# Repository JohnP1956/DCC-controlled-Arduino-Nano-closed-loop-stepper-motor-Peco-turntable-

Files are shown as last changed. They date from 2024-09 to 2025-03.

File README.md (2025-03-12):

This is my project to construct a OO gauge Peco turntable kit motorised with a Makerbase MKS42D closed loop stepper motor.  The construction details are in the RMweb link.  The user guide for the motor is attached as is the arduino code I developed to control the motor.  The code was developed using AI (Chat GPT, CoPilot and Claude) as I am not a coder.  I have also added a demo code for controling the turntable system with RR&CO Train Controller (Gold).
I recently noticed that MKS have updated their product to a serial commanded motor only.  However, the motor I used and its previous incarnation plus the kit to add a closed loop board to any NEMA 17 motor are still available on Aliexpress at the time of writing this README note (March 2025).
Readers should note that the PCB does not include a 5volt connection for the stepper motor.  This is bacause the original wiring information for the motor did not include the need for the 5 volt connection.  I used a direct wire to the VCC terminal of the hall detector connection on the pcb.  You can either do the same, wire a shunt wire on the underside of the pcb or update the pcb layout.  Either way the 5 volt connetion (white wire on the motor lead) must be connected or the motor will not move.

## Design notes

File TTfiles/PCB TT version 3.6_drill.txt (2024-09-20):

; NON-PLATED HOLES START AT T1
; THROUGH (PLATED) HOLES START AT T100
M48
INCH
T1C0.086614
T100C0.036000
T101C0.027559
T102C0.038000
T103C0.040000
T104C0.035000
T105C0.035433
T106C0.015748
T107C0.042000
%
T1
X036866Y019914
X036866Y001734
X002614Y001734
T100
X013722Y005381
X003722Y011381
X004722Y005381
X014722Y011381
X003722Y005381
X014722Y005381
X004722Y011381
X013722Y011381
X006722Y005381
X009722Y011381
X016722Y011381
X011722Y005381
X010722Y011381
X012722Y005381
X002722Y011381
X008722Y005381
X005722Y005381
X007722Y005381
X015722Y011381
X015722Y005381
X005722Y011381
X007722Y011381
X002722Y005381
X012722Y011381
X008722Y011381
X011722Y011381
X010722Y005381
X016722Y005381
X006722Y011381
X009722Y005381
T101
X022663Y016424
X025108Y003279
X032722Y007381
X029722Y005381
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

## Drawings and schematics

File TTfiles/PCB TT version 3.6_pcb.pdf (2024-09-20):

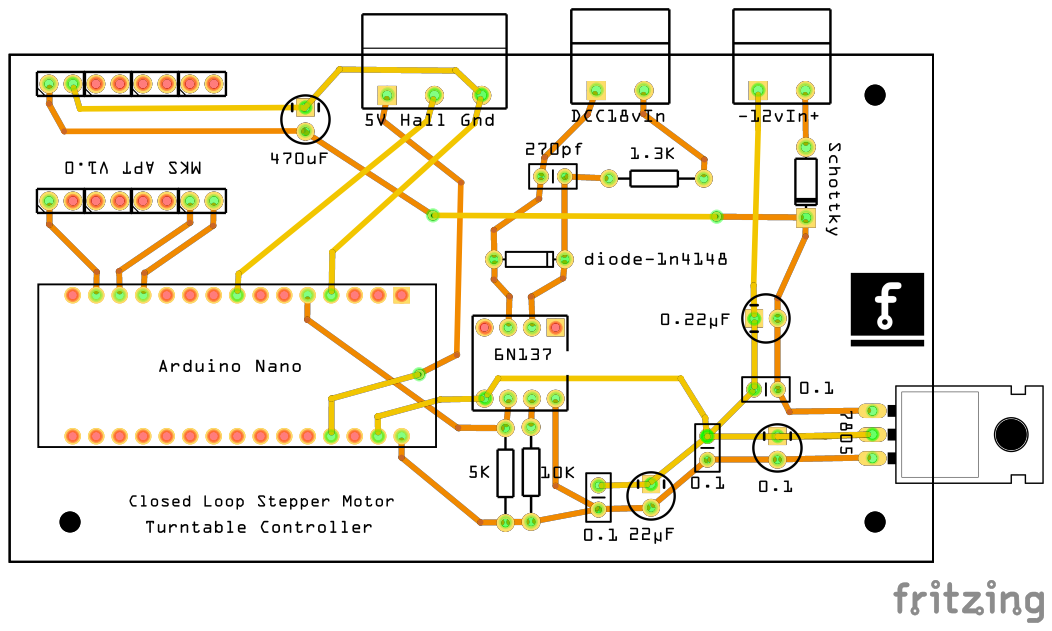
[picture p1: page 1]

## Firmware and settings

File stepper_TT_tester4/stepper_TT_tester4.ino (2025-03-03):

/*
 * Stepper Motor Turntable Control with DCC Commands
 *
 * This software controls a stepper motor for a model railway turntable, using DCC commands
 * to move the turntable to various indexed positions. It supports an iterative setup process
 * for configuring index positions, storing configurations in EEPROM, and ensuring compliance
 * with NMRA DCC standards.
 *
 * Key Features:
 * - DCC control with address validation (addresses 1-511).
 * - Iterative setup process with EEPROM storage and `EEPROM.update()` for efficient writes.
 * - Configurable homing direction (clockwise or counter-clockwise, default is now counter-clockwise).
 * - Debug mode for serial communication during setup.
 * - It allows for iterative setup of each index position, viewing and modifying stored positions,
 *  -and uses EEPROM.update() to write only if a value changes.
 * - Supports 1.8-degree stepper motor with 32x microstepping (6400 steps per revolution).
 * - Configurable number of index positions (1-12)
 * - License: MIT License (see below).
 *
 * Libraries Used:
 * - AccelStepper: https://www.airspayce.com/mikem/arduino/AccelStepper/
 * - NmraDcc: https://github.com/mrrwa/NmraDcc
 *
 * Author: JP1 c/o RM Web
 * Date: 20/07/2024
 *
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
 */

#include <AccelStepper.h>
#include <NmraDcc.h>
#include <EEPROM.h>
#include "config.h"

// Create an instance of the AccelStepper class
AccelStepper stepper(MotorInterfaceType, stepPin, dirPin);

// Create an instance of the DCC decoder
NmraDcc Dcc;

// Position-related variables
long magnetEndPositions[MAX_INDEX_POSITIONS];    // Positions for magnet end, stored in EEPROM
long nonMagnetEndPositions[MAX_INDEX_POSITIONS]; // Positions for non-magnet end, stored in EEPROM
long currentPosition = 0;
bool homed = false;

// DCC addresses
int homePositionAddress;
int magnetEndAddresses[MAX_INDEX_POSITIONS];
int nonMagnetEndAddresses[MAX_INDEX_POSITIONS];
int numIndexPositions;  // Number of index positions, stored in EEPROM

// Last Address variables to prevent duplicate events
uint16_t lastAddr = 0xFFFF;
uint8_t lastDirection = 0xFF;

// Function prototypes
int getValidDccAddress();
int getValidIndexNumber();
void debugSetup();
String getUserInput();
long getUserInputLong();
bool getUserYesNo();
void loadConfigurations();
void homeMotor();
void moveToPosition(long position);
void moveRelative(long steps);
int calculateShortestStepDifference(long currentPosition, long nextPosition);

void setup() {
  Serial.begin(9600); // Start serial communication for debugging

  // Initialize pins
  pinMode(enPin, OUTPUT);
  pinMode(hallPin, INPUT_PULLUP);
  pinMode(stepPin, OUTPUT);
  pinMode(dirPin, OUTPUT);
  digitalWrite(enPin, LOW); // Enable the motor

  // Set max speed and acceleration
  stepper.setMaxSpeed(maxSpeed);
  stepper.setAcceleration(acceleration);

  Serial.println(F("Setup complete, loading configurations..."));

  // Load configurations from EEPROM
  loadConfigurations();

  // Initialize DCC decoder
  Dcc.pin(0,DCC_PIN, 1);
  Dcc.init(MAN_ID_DIY, 10, CV29_ACCESSORY_DECODER | CV29_OUTPUT_ADDRESS_MODE, 0);// Adjust manufacturer ID and version as needed
  Serial.println(F("DCC decoder initialized"));
  
  // Home the motor at startup
  homeMotor();

  // Call the debug setup function if debugging is enabled
  if (debug) {
    Serial.println(F("Debug mode enabled. Calling debug setup..."));
    debugSetup();
    Serial.println(F("Returned from debug setup..."));
  }
}

void loop() {
  // Process DCC commands
  Dcc.process();

  // Ensure the motor is running
  stepper.run();
}

// DCC command notification handler
void notifyDccAccTurnoutOutput(uint16_t Addr, uint8_t Direction, uint8_t OutputPower) {
  Serial.print(F("DCC Command Received - Address: "));
  Serial.print(Addr);
  Serial.print(F(" Direction: "));
  Serial.print(Direction);
  Serial.print(F(" Power: "));
  Serial.println(OutputPower);

  if (OutputPower) {
    if (Addr == homePositionAddress) {
      Serial.println(F("Moving to home position..."));
      moveRelative(-currentPosition);
      return;
    }

    for (int i = 0; i < numIndexPositions; i++) {
      if (Addr == magnetEndAddresses[i]) {
        Serial.print(F("Moving to magnet end position: "));
        Serial.println(magnetEndPositions[i]);
        long stepsToMove = calculateShortestStepDifference(currentPosition, magnetEndPositions[i]);
        moveRelative(stepsToMove);
        return;
      } else if (Addr == nonMagnetEndAddresses[i]) {
        Serial.print(F("Moving to non-magnet end position: "));
        Serial.println(nonMagnetEndPositions[i]);
        long stepsToMove = calculateShortestStepDifference(currentPosition, nonMagnetEndPositions[i]);
        moveRelative(stepsToMove);
        return;
      }
    }
  }
}

void homeMotor() {
    Serial.println(F("Starting homing process..."));

    // Initialize the counter for Hall sensor triggers
    int hallSensorTriggerCount = 0;

    // Set the speed and direction for the homing movement
    stepper.setSpeed(homingDirection ? maxSpeed : -maxSpeed);

    // Debugging print to confirm the direction
    Serial.print(F("Homing motor in direction: "));
    Serial.println(homingDirection ? F("Counter-Clockwise") : F("Clockwise"));

    // Move until the Hall sensor is triggered twice
    bool sensorPreviouslyTriggered = false;
    while (hallSensorTriggerCount < 2) {
        stepper.runSpeed();
        bool sensorCurrentlyTriggered = (digitalRead(hallPin) == LOW);
        if (sensorCurrentlyTriggered && !sensorPreviouslyTriggered) { // Rising edge detection
            hallSensorTriggerCount++;
            Serial.print(F("Hall sensor triggered "));
            Serial.print(hallSensorTriggerCount);
            Serial.println(F(" time(s)"));
        }
        sensorPreviouslyTriggered = sensorCurrentlyTriggered;
    }

    // Set the home position
    stepper.setCurrentPosition(0);
    currentPosition = 0;
    homed = true;

    Serial.println(F("Homing process completed."));
    Serial.println(F("Exiting homeMotor function"));

    // Response after homing
    Serial.println(F("Motor homed successfully."));

    // Small delay to allow hall sensor state to stabilize
    delay(500);
}

void moveToPosition(long position) {
  if (!homed) homeMotor();
  long stepsToMove = calculateShortestStepDifference(currentPosition, position);
  moveRelative(stepsToMove);
}

// Modified version of moveRelative to handle the special case
void moveRelative(long steps) {
  // Special case: moving to zero from a position more than half a revolution away
  if (steps == -currentPosition && abs(currentPosition) > stepsPerRevolution / 2) {
    Serial.println(F("Special case: Moving to zero position using homing-like approach"));
    
    // Set the speed for counterclockwise rotation (use the same direction as homing)
    stepper.setSpeed(homingDirection ? maxSpeed : -maxSpeed);
    
    // Initialize variables for hall sensor detection
    bool sensorPreviouslyTriggered = false;
    int hallSensorTriggerCount = 0;
    
    // Run until we trigger the hall sensor twice (just like in homing)
    while (hallSensorTriggerCount < 1) {
        stepper.runSpeed();
        bool sensorCurrentlyTriggered = (digitalRead(hallPin) == LOW);
        
        if (sensorCurrentlyTriggered && !sensorPreviouslyTriggered) { 
            hallSensorTriggerCount++;
            //Serial.print(F("Hall sensor triggered "));
            //Serial.print(hallSensorTriggerCount);
            //Serial.println(F(" time(s) during move to zero"));
        }
        sensorPreviouslyTriggered = sensorCurrentlyTriggered;
    }
    
    // Reset position tracking
    stepper.setCurrentPosition(0);
    currentPosition = 0;
    
    // Small delay to allow hall sensor state to stabilize
    delay(500);
    
    Serial.println(F("Special move to zero completed successfully"));
  } 
  // Normal case: use the existing movement code
  else {
    stepper.move(steps);
    while (stepper.distanceToGo() != 0) {
      stepper.run();
    }
    currentPosition += steps;
  }
}

// Define the loadConfigurations function
void loadConfigurations() {
  Serial.println(F("Loading configurations from EEPROM..."));

  // Load the home position address from EEPROM
  EEPROM.get(EEPROM_HOME_ADDRESS, homePositionAddress);
  Serial.print(F("Home Position Address       : "));
  Serial.println(homePositionAddress);

  // Load the number of index positions from EEPROM
  EEPROM.get(EEPROM_NUM_INDEX_POSITIONS, numIndexPositions);
  
  // Validate numIndexPositions
  if (numIndexPositions < 1 || numIndexPositions > MAX_INDEX_POSITIONS) {
    numIndexPositions = 1;  // Default to 1 if invalid
    EEPROM.put(EEPROM_NUM_INDEX_POSITIONS, numIndexPositions);
  }
  
  Serial.print(F("Number of Index Positions   : "));
  Serial.println(numIndexPositions);

  // Load the positions for magnet and non-magnet ends from EEPROM
  for (int i = 0; i < numIndexPositions; i++) {
    EEPROM.get(EEPROM_MAGNET_POSITIONS + i * sizeof(long), magnetEndPositions[i]);
    EEPROM.get(EEPROM_NON_MAGNET_POSITIONS + i * sizeof(long), nonMagnetEndPositions[i]);

    Serial.print(F("Magnet End Position     ["));
    Serial.print(i + 1);
    Serial.print(F("] : "));
    Serial.println(magnetEndPositions[i]);

    Serial.print(F("Non-Magnet End Position ["));
    Serial.print(i + 1);
    Serial.print(F("] : "));
    Serial.println(nonMagnetEndPositions[i]);
  }

  // Calculate index addresses based on home address
  for (int i = 0; i < numIndexPositions; i++) {
    magnetEndAddresses[i] = homePositionAddress + (2 * i) + 1;
    nonMagnetEndAddresses[i] = homePositionAddress + (2 * i) + 2;

    Serial.print(F("Magnet End Address      ["));
    Serial.print(i + 1);
    Serial.print(F("] : "));
    Serial.println(magnetEndAddresses[i]);

    Serial.print(F("Non-Magnet End Address  ["));
    Serial.print(i + 1);
    Serial.print(F("] : "));
    Serial.println(nonMagnetEndAddresses[i]);
  }
}

int getValidDccAddress() {
  int address = 0;
  while (true) {
    Serial.println(F("Enter a DCC address (1-511):"));
    address = getUserInputLong();
    if (address >= 1 && address <= 511) {
      return address;
    } else {
      Serial.println(F("Invalid address. Please enter a number between 1 and 511:"));
    }
  }
}

int getValidIndexNumber() {
  int number = 0;
  while (true) {
    Serial.print(F("Enter the number of index positions (1-"));
    Serial.print(MAX_INDEX_POSITIONS);
    Serial.println(F("):"));
    number = getUserInputLong();
    if (number >= 1 && number <= MAX_INDEX_POSITIONS) {
      return number;
    } else {
      Serial.print(F("Invalid number. Please enter a number between 1 and "));
      Serial.print(MAX_INDEX_POSITIONS);
      Serial.println(F(":"));
    }
  }
}

// Utility function to get user input as a String
String getUserInput() {
  while (Serial.available() == 0) {
    // Wait for user input
  }
  String input = Serial.readStringUntil('\n');
  input.trim(); // Remove any trailing newline or carriage return characters
  return input;
}

// Utility function to get user input as a long
long getUserInputLong() {
  String input = getUserInput();
  return input.toInt();
}

// Utility function to get user input as a yes/no response
bool getUserYesNo() {
  while (Serial.available() == 0) {
    // Wait for user input
  }
  String input = Serial.readStringUntil('\n');
  input.trim(); // Remove any trailing newline or carriage return characters
  return (input.equalsIgnoreCase("y"));
}

// Debugging Setup Code for Stepper Motor Turntable
// This code is included only when the 'debug' flag is true.

void debugSetup() {
    Serial.println(F("Starting setup in debug mode..."));

    // Get or set home DCC address
    Serial.println(F("First, let's configure the home position DCC address."));
    EEPROM.get(EEPROM_HOME_ADDRESS, homePositionAddress);
    
    Serial.print(F("Current home position address: "));
    Serial.println(homePositionAddress);
    Serial.println(F("Do you want to change this address? (y/n):"));
    
    if (getUserYesNo() || homePositionAddress < 1 || homePositionAddress > 511) {
        homePositionAddress = getValidDccAddress();
        EEPROM.put(EEPROM_HOME_ADDRESS, homePositionAddress);
        Serial.print(F("Home position address set to: "));
        Serial.println(homePositionAddress);
    }

    // Get or set number of index positions - ALWAYS ASK THE USER
    Serial.println(F("Now, let's configure the number of index positions."));
    EEPROM.get(EEPROM_NUM_INDEX_POSITIONS, numIndexPositions);
    
    Serial.print(F("Current number of index positions: "));
    Serial.println(numIndexPositions);
    Serial.println(F("Do you want to change the number of index positions? (y/n):"));
    
    if (getUserYesNo() || numIndexPositions < 1 || numIndexPositions > MAX_INDEX_POSITIONS) {
        numIndexPositions = getValidIndexNumber();
        EEPROM.put(EEPROM_NUM_INDEX_POSITIONS, numIndexPositions);
        Serial.print(F("Number of index positions set to: "));
        Serial.println(numIndexPositions);
    }

    // Calculate index addresses based on home address - addresses go in pairs
    Serial.println(F("Calculating DCC addresses for index positions..."));
    for (int i = 0; i < numIndexPositions; i++) {
        magnetEndAddresses[i] = homePositionAddress + (2 * i) + 1;
        nonMagnetEndAddresses[i] = homePositionAddress + (2 * i) + 2;
        
        Serial.print(F("Index "));
        Serial.print(i + 1);
        Serial.print(F(" - Magnet End Address: "));
        Serial.print(magnetEndAddresses[i]);
        Serial.print(F(", Non-Magnet End Address: "));
        Serial.println(nonMagnetEndAddresses[i]);
    }

    // Iteratively set positions for each index
    Serial.println(F("\nNow let's setup the physical positions for each index."));
    Serial.println(F("Setting up magnet end positions..."));
    
    for (int i = 0; i < numIndexPositions; i++) {
        bool positionAccepted = false;
        while (!positionAccepted) {
            // Load existing positions
            EEPROM.get(EEPROM_MAGNET_POSITIONS + i * sizeof(long), magnetEndPositions[i]);

            Serial.print(F("\nIndex "));
            Serial.print(i + 1);
            Serial.println(F(" Magnet End:"));

            Serial.print(F("Current Position (steps): "));
            Serial.println(magnetEndPositions[i]);
            Serial.println(F("Do you want to modify this position? (y/n): "));
            
            if (getUserYesNo()) {
                Serial.println(F("Enter new Magnet End Position (steps): "));
                long newPosition = getUserInputLong();
                EEPROM.put(EEPROM_MAGNET_POSITIONS + i * sizeof(long), newPosition);
                magnetEndPositions[i] = newPosition;
                Serial.println(F("Position updated."));
                moveRelative(magnetEndPositions[i] - currentPosition); // Move the stepper to the new position

                // Ask for user confirmation for the new position
                Serial.println(F("Do you accept this new position? (y/n): "));
                positionAccepted = getUserYesNo();
                if (!positionAccepted) {
                    Serial.println(F("Re-enter the position..."));
                }
            } else {
                Serial.println(F("Position accepted without changes."));
                positionAccepted = true;
            }
        }
    }

    Serial.println(F("\nSetting up non-magnet end positions..."));
    for (int i = 0; i < numIndexPositions; i++) {
        bool positionAccepted = false;
        while (!positionAccepted) {
            // Load existing positions
            EEPROM.get(EEPROM_NON_MAGNET_POSITIONS + i * sizeof(long), nonMagnetEndPositions[i]);

            Serial.print(F("\nIndex "));
            Serial.print(i + 1);
            Serial.println(F(" Non-Magnet End:"));

            Serial.print(F("Current Position (steps): "));
            Serial.println(nonMagnetEndPositions[i]);
            Serial.println(F("Do you want to modify this position? (y/n): "));
            
            if (getUserYesNo()) {
                Serial.println(F("Enter new Non-Magnet End Position (steps): "));
                long newPosition = getUserInputLong();
                EEPROM.put(EEPROM_NON_MAGNET_POSITIONS + i * sizeof(long), newPosition);
                nonMagnetEndPositions[i] = newPosition;
                Serial.println(F("Position updated."));
                moveRelative(nonMagnetEndPositions[i] - currentPosition); // Move the stepper to the new position

                // Ask for user confirmation for the new position
                Serial.println(F("Do you accept this new position? (y/n): "));
                positionAccepted = getUserYesNo();
                if (!positionAccepted) {
                    Serial.println(F("Re-enter the position..."));
                }
            } else {
                Serial.println(F("Position accepted without changes."));
                positionAccepted = true;
            }
        }
    }

    // Summary of configurations
    Serial.println(F("\n==== Configuration Summary ===="));
    Serial.print(F("Home Position Address: "));
    Serial.println(homePositionAddress);
    Serial.print(F("Number of Index Positions: "));
    Serial.println(numIndexPositions);
    
    for (int i = 0; i < numIndexPositions; i++) {
        Serial.print(F("\nIndex "));
        Serial.print(i + 1);
        Serial.println(F(":"));
        
        Serial.print(F("  Magnet End - Address: "));
        Serial.print(magnetEndAddresses[i]);
        Serial.print(F(", Position: "));
        Serial.println(magnetEndPositions[i]);
        
        Serial.print(F("  Non-Magnet End - Address: "));
        Serial.print(nonMagnetEndAddresses[i]);
        Serial.print(F(", Position: "));
        Serial.println(nonMagnetEndPositions[i]);
    }

    Serial.println(F("\nSetup completed successfully."));
}

// Function to calculate the shortest step difference between current and next positions
int calculateShortestStepDifference(long currentPosition, long nextPosition) {
  // For regular moves not involving home position
  if (nextPosition != 0) {
    long stepDifference = nextPosition - currentPosition;
    
    // If the absolute difference is greater than half a revolution,
    // then we should go the other way around
    if (abs(stepDifference) > stepsPerRevolution / 2) {
      if (stepDifference > 0) {
        return stepDifference - stepsPerRevolution;
      } else {
        return stepDifference + stepsPerRevolution;
      }
    }
    
    return stepDifference;
  }
  
  // For moves to home position (zero)
  else {
    return -currentPosition;
  }
}

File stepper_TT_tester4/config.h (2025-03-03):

#ifndef CONFIG_H
#define CONFIG_H

// Define stepper motor interface type
#define MotorInterfaceType 1

// Pin connections
const int stepPin = 10;         // Step signal to stepper driver
const int dirPin = 9;           // Direction signal to stepper driver
const int enPin = 11;           // Enable signal to stepper driver
const int hallPin = 5;          // Hall effect sensor input
const int DCC_PIN = 2;          // DCC input via optocoupler

// Stepper motor settings
const int stepsPerRevolution = 6400; // 1.8-degree motor with 32x microstepping
const float maxSpeed = 142.22;       // Max speed (steps per second) for 45 seconds per revolution
const float acceleration = 16.0;    // Acceleration (steps per second squared)

// Maximum number of index positions
const int MAX_INDEX_POSITIONS = 12;

// EEPROM storage addresses
const int EEPROM_START_ADDRESS = 100;
const int EEPROM_HOME_ADDRESS = EEPROM_START_ADDRESS;
const int EEPROM_NUM_INDEX_POSITIONS = EEPROM_HOME_ADDRESS + sizeof(int);
const int EEPROM_MAGNET_POSITIONS = EEPROM_NUM_INDEX_POSITIONS + sizeof(int);
const int EEPROM_NON_MAGNET_POSITIONS = EEPROM_MAGNET_POSITIONS + sizeof(long) * MAX_INDEX_POSITIONS;

// Homing direction (true for counter-clockwise, false for clockwise)
const bool homingDirection = true; // True for CCW. Check motor default direction if movement is opposite.

// Debug flag
const bool debug = false; // Set to true for debugging

#endif // CONFIG_H
